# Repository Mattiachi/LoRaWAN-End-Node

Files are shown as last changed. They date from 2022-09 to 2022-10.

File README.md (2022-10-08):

# LoRaWAN-End-Node
Project HW and FW of a LoRaWAN end-node with a low power consumption &lt; 1uW

This project is based on a PIC18LF46K22 and the LoRaWAN transceiver SX1276.
The board is powered up by two AAA batteries in series and stays in sleep with a current of around 50 nA. 
After an amount of time set by the resistance Rext, the timer TPL5010 wakes up the PIC18, wich is responsible of measuring the temperature and sending it to a nearby LoRaWAN gateway via ABP (Activation by Personalization).

With this arrangement, transmitting every 15-30 minutes at the lowest SF possible, the estimated life battery can range between 2 to 8 years.

There is a wake button, wich can instantly wake up the board, a ICSP programming port for PICKIT3 or 4 and two rows of 8 pins (distanced 2.54mm) that allow to solder on top of the PCB the [LoRa Olimex module](https://www.olimex.com/Products/IoT/LoRa/LoRa868/open-source-hardware). 

For further information refer to my [thesis document](https://amslaurea.unibo.it/26629)
where the project is explained in more detail.

MicrosoftTeams-image (10) 3d_view_bakc
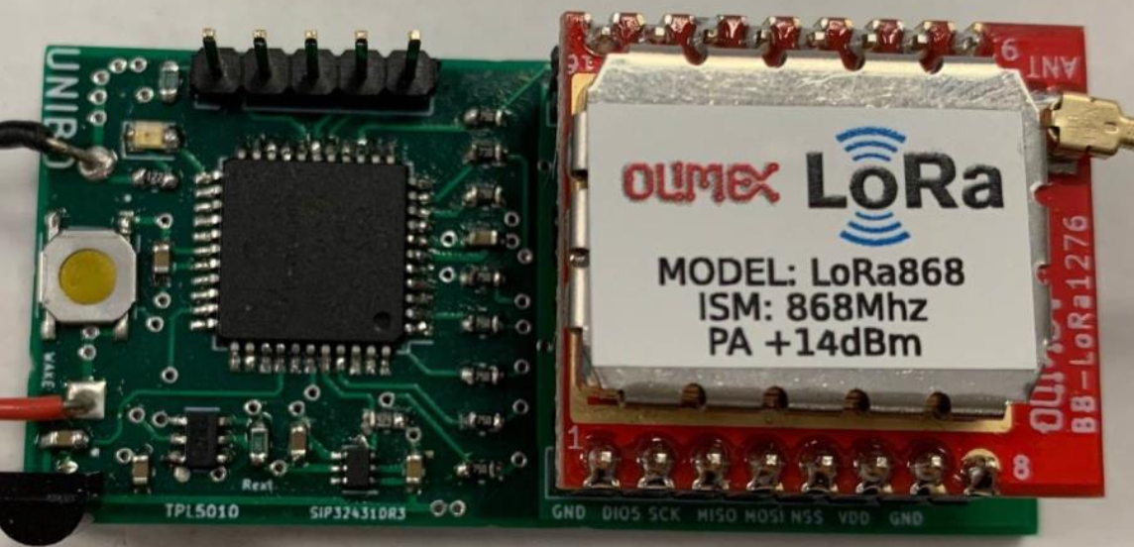
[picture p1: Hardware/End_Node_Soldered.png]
End_Node_Soldered


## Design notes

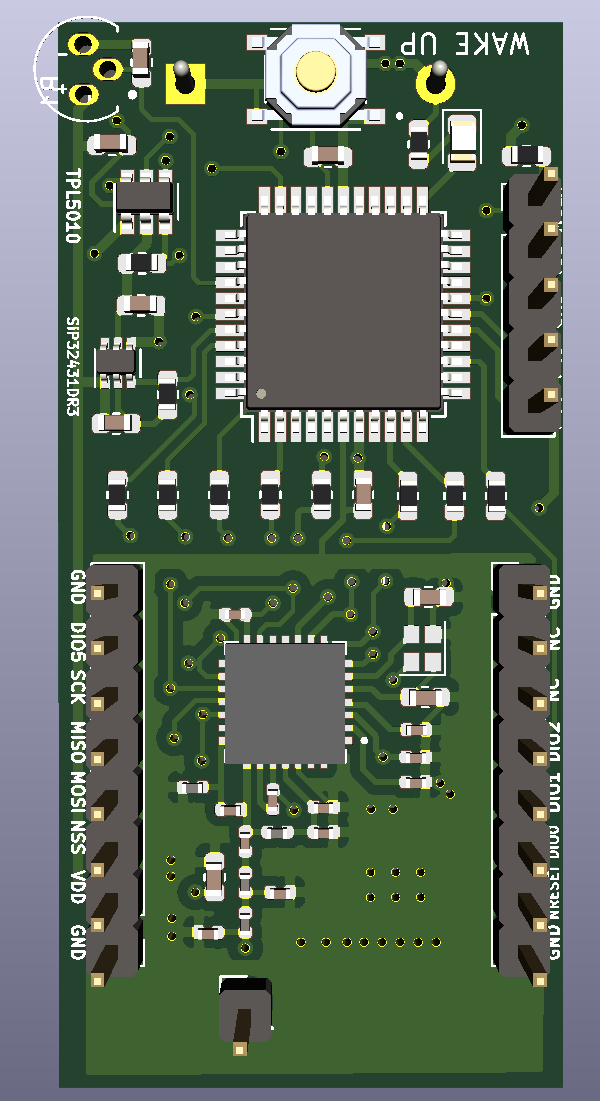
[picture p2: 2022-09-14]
Hardware/3d_view.PNG

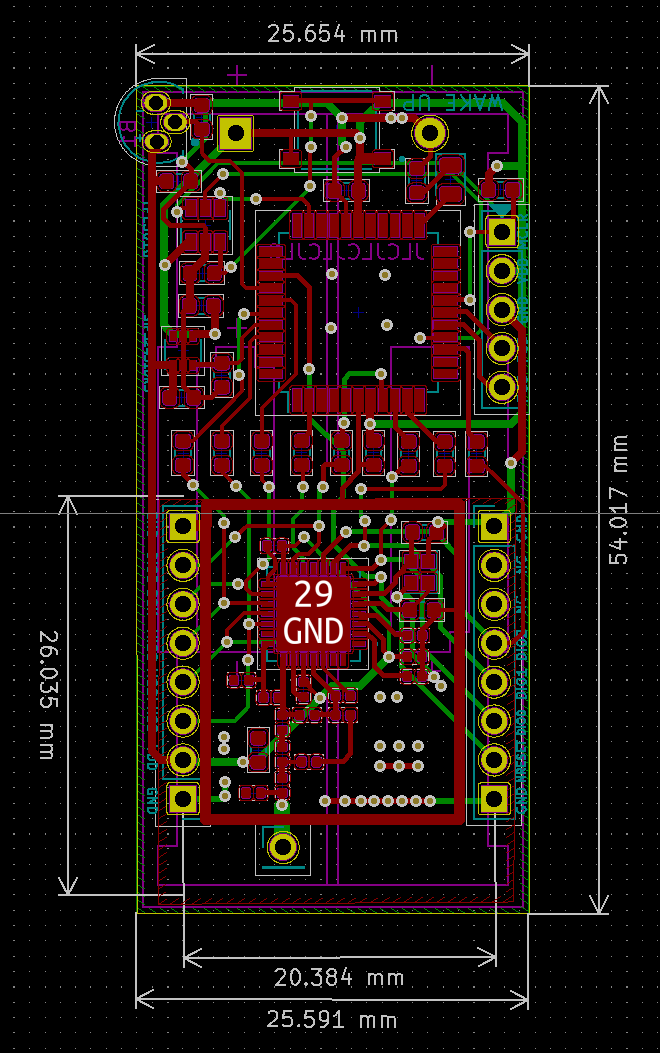
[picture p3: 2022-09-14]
Hardware/layout.PNG

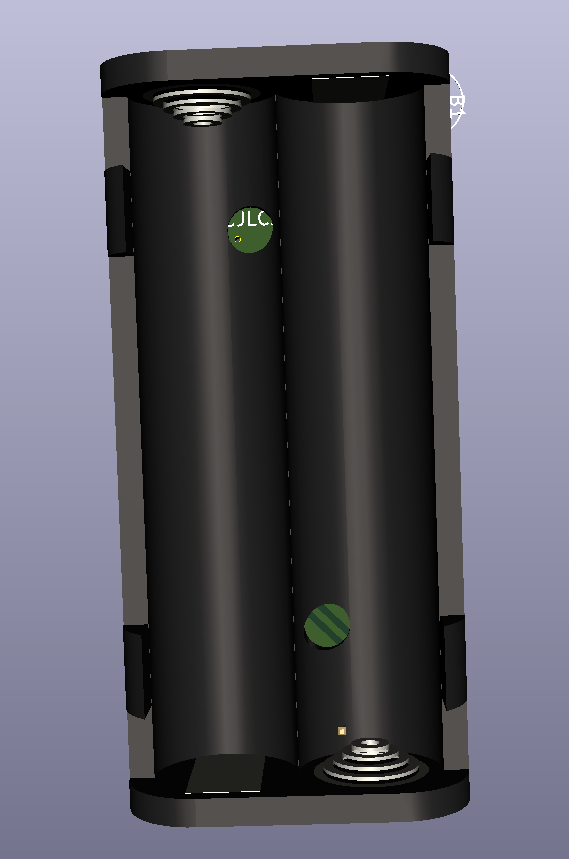
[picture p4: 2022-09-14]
Hardware/3d_view_bakc.PNG

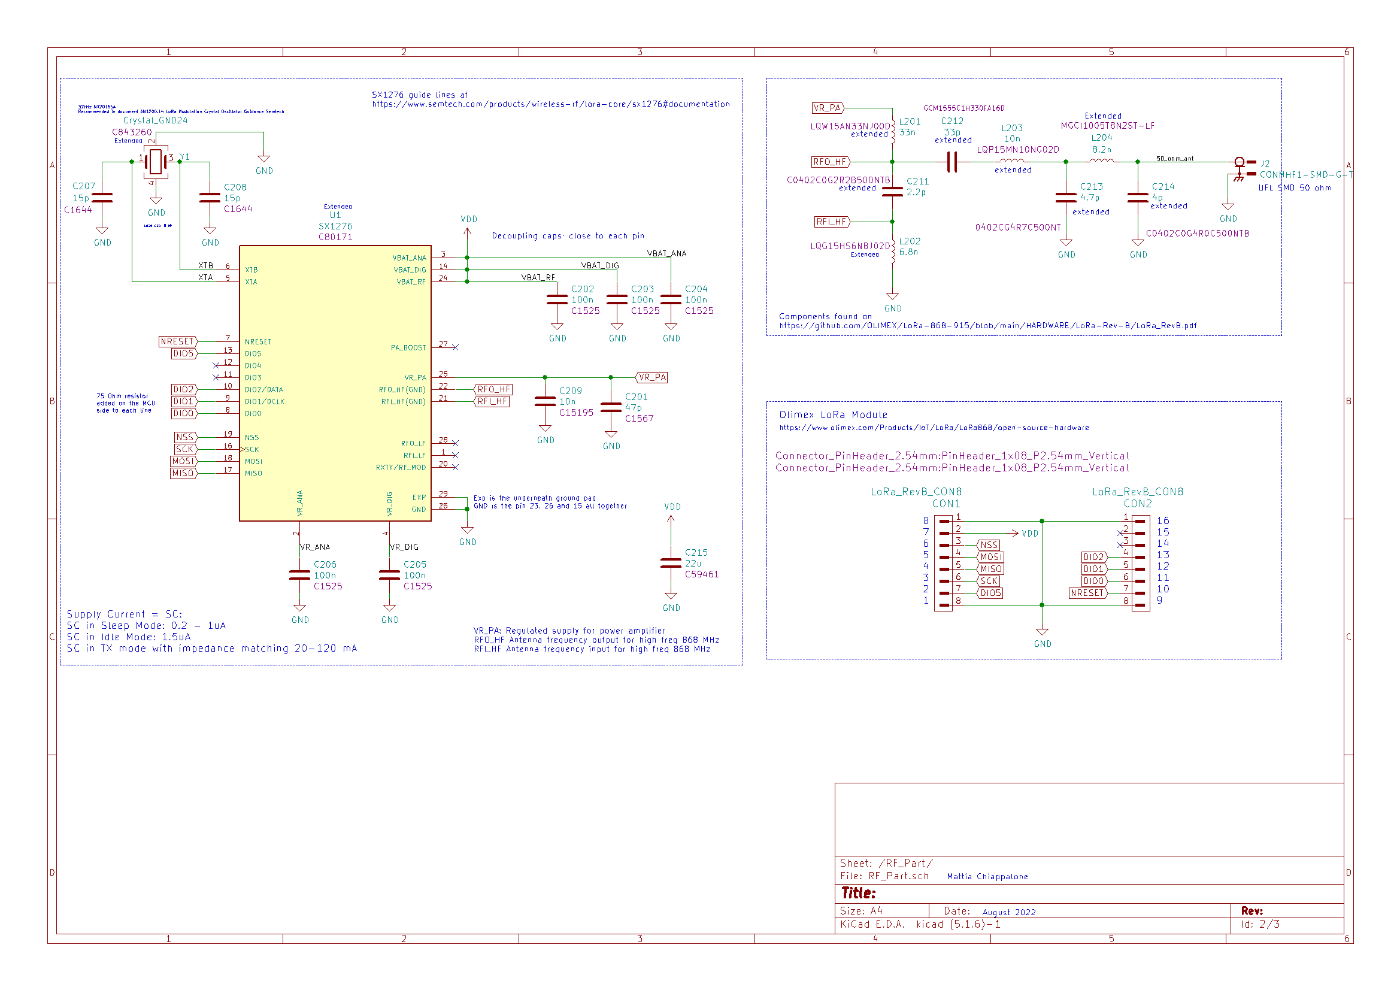
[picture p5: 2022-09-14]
Schematic/RF_part.png

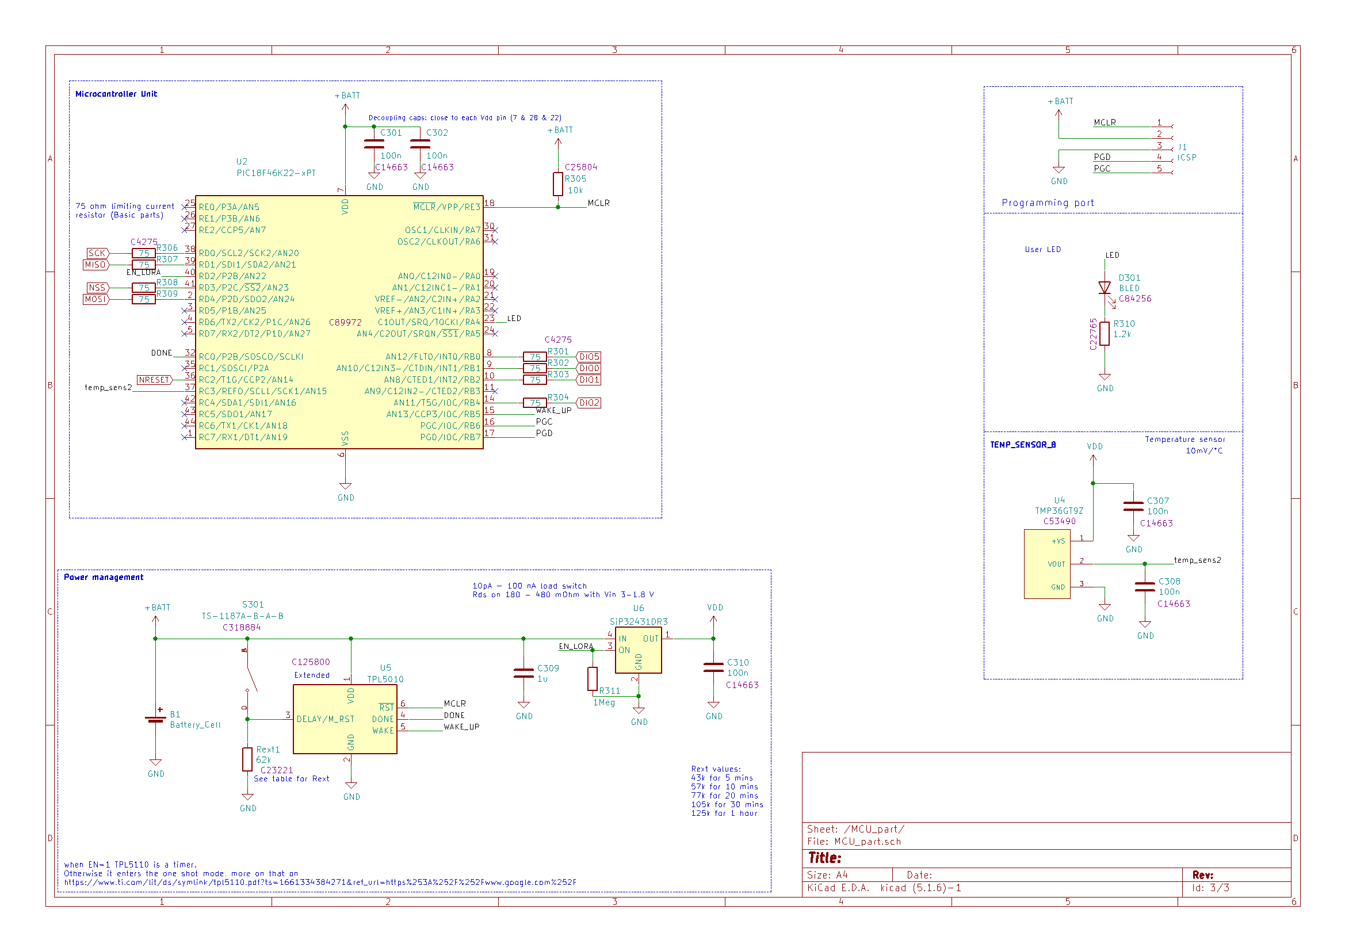
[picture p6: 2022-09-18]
Schematic/mcu.png

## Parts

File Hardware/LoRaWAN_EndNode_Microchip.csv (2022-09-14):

Comment | Designator | Footprint | LCSC | Extended | MPN
Battery_Cell | B1 | Battery_Holders:Keystone_2468_2xAAA |  |  | keystone 2468
47p | C201 | Capacitor_SMD:C_0402_1005Metric | C1567 | No | 0402CG470J500NT
100n | C202,C203,C204,C205,C206 | Capacitor_SMD:C_0402_1005Metric | C1525 | No | CL05B104KO5NNNC
15p | C207,C208 | Capacitor_SMD:C_0603_1608Metric | C1644 | No | CL10C150JB8NNNC
10n | C209 | Capacitor_SMD:C_0402_1005Metric | C15195 | No | CL05B103KB5NNNC
47n | C210 | Capacitor_SMD:C_0603_1608Metric | C1622 | No | CL10B473KB8NNNC
2.2p | C211 | Capacitor_SMD:C_0402_1005Metric | C140673 | Yes | C0402C0G2R2B500NTB
33p | C212 | Capacitor_SMD:C_0402_1005Metric | C437439 | Yes | GCM1555C1H330FA16D
4.7p | C213 | Capacitor_SMD:C_0402_1005Metric | C1569 | No | 0402CG4R7C500NT
4p | C214 | Capacitor_SMD:C_0402_1005Metric | C140662 | Yes | C0402C0G4R0C500NTB
10u | C303 | Capacitor_SMD:C_0603_1608Metric | C96446 | No | CL10A106MA8NRNC
1u | C304,C309 | Capacitor_SMD:C_0603_1608Metric | C15849 | No | CL10A105KB8NNNC
100n | C301,C302,C305,C306,C307,C308,C310 | Capacitor_SMD:C_0603_1608Metric | C14663 | No | CC0603KRX7R9BB104
LoRa_RevB_CON8 | CON1,CON2 | Connector_PinHeader_2.54mm:PinHeader_1x08_P2.54mm_Vertical |  | No
BLED | D301 | LED_SMD:LED_0805_2012Metric | C84256 | No | NCD0805R1
ICSP | J1 | Connector_PinHeader_2.54mm:PinHeader_1x05_P2.54mm_Vertical
Antenna connector | J2 | Connector_PinHeader_2.54mm:PinHeader_1x01_P2.54mm_Vertical
33n | L201 | Inductor_SMD:L_0402_1005Metric | C335624 | Yes | LQW15AN33NJ00D
6.8n | L202 | Inductor_SMD:L_0402_1005Metric | C77110 | Yes | LQG15HS6N8J02D
10n | L203 | Inductor_SMD:L_0402_1005Metric | C162639 | Yes | LQP15MN10NG02D
8.2n | L204 | Inductor_SMD:L_0402_1005Metric | C281010 | Yes | MGCI1005T8N2ST-LF
10k | R305,R311 | Resistor_SMD:R_0603_1608Metric | C25804 | No | 0603WAF1002T5E
75 | R301,R302,R303,R304,R306,R307,R308,R309 | Resistor_SMD:R_0603_1608Metric | C4275 | No | 0603WAF750JT5E
1.2k | R310 | Resistor_SMD:R_0603_1608Metric | C22765 | No | 0603WAF1201T5E
62k | Rext1 | Resistor_SMD:R_0603_1608Metric | C23221 | No | 0603WAF6202T5E
TS-1187A-B-A-B | S301 | SW_TS-1187A-B-A-B | C318884 | No | TS-1187A-B-A-B
SX1276 | U1 | QFN65P600X600X100-29N | C80171 | Yes | SX1276IMLTRT
PIC18F46K22-xPT | U2 | Package_QFP:TQFP-44_10x10mm_P0.8mm | C89972 | Yes | PIC18F46K22-I/PT
MCP9700AT-ETT | U3 | Package_TO_SOT_SMD:SOT-23 | C127949 | Yes | MCP9700AT-E/TT
TMP36GT9Z | U4 | TO92127P521H733-3 | C53490 | Yes | TMP36GT9Z
TPL5010 | U5 | Package_TO_SOT_SMD:SOT-23-6 | C125800 | Yes | TPL5010DDCT
SiP32431DR3 | U6 | Package_TO_SOT_SMD:SOT-363_SC-70-6 | C141606 | Yes | SIP32431DR3-T1GE3
Crystal_GND24 | Y1 | Crystal:Crystal_SMD_2016-4Pin_2.0x1.6mm | C843260 | Yes | NX2016SA-32MHZ-STD-CZS-5

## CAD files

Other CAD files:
FW/dist/default/production/ZZZZZZ.production.obj

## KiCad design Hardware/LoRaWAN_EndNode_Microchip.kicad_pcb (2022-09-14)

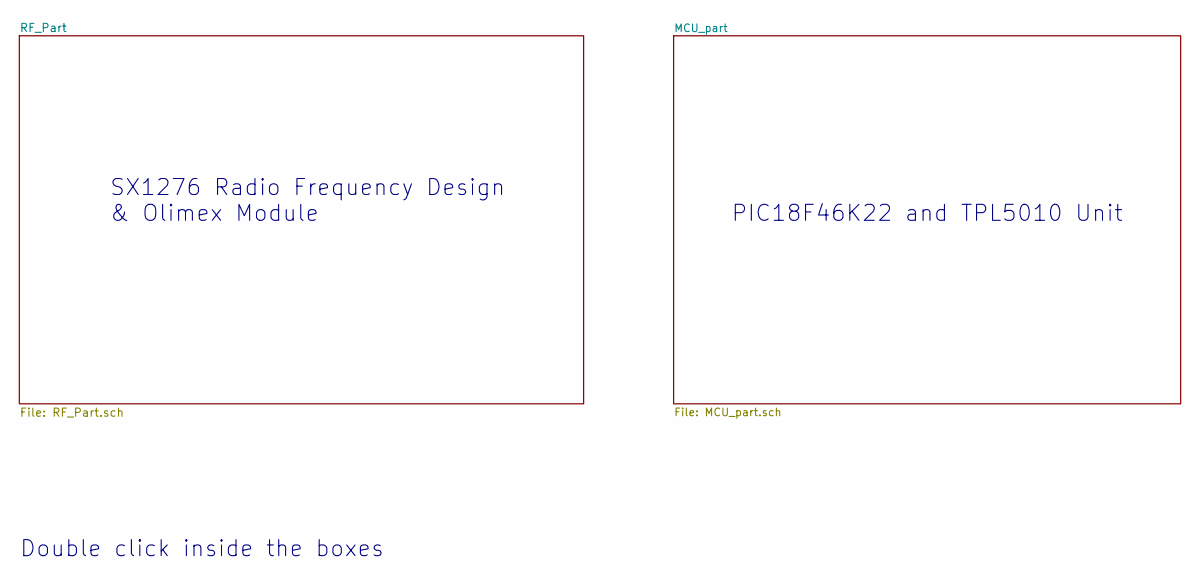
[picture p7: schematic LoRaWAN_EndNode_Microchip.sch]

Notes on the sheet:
SX1276 Radio Frequency Design & Olimex Module
PIC18F46K22 and TPL5010 Unit
Double click inside the boxes

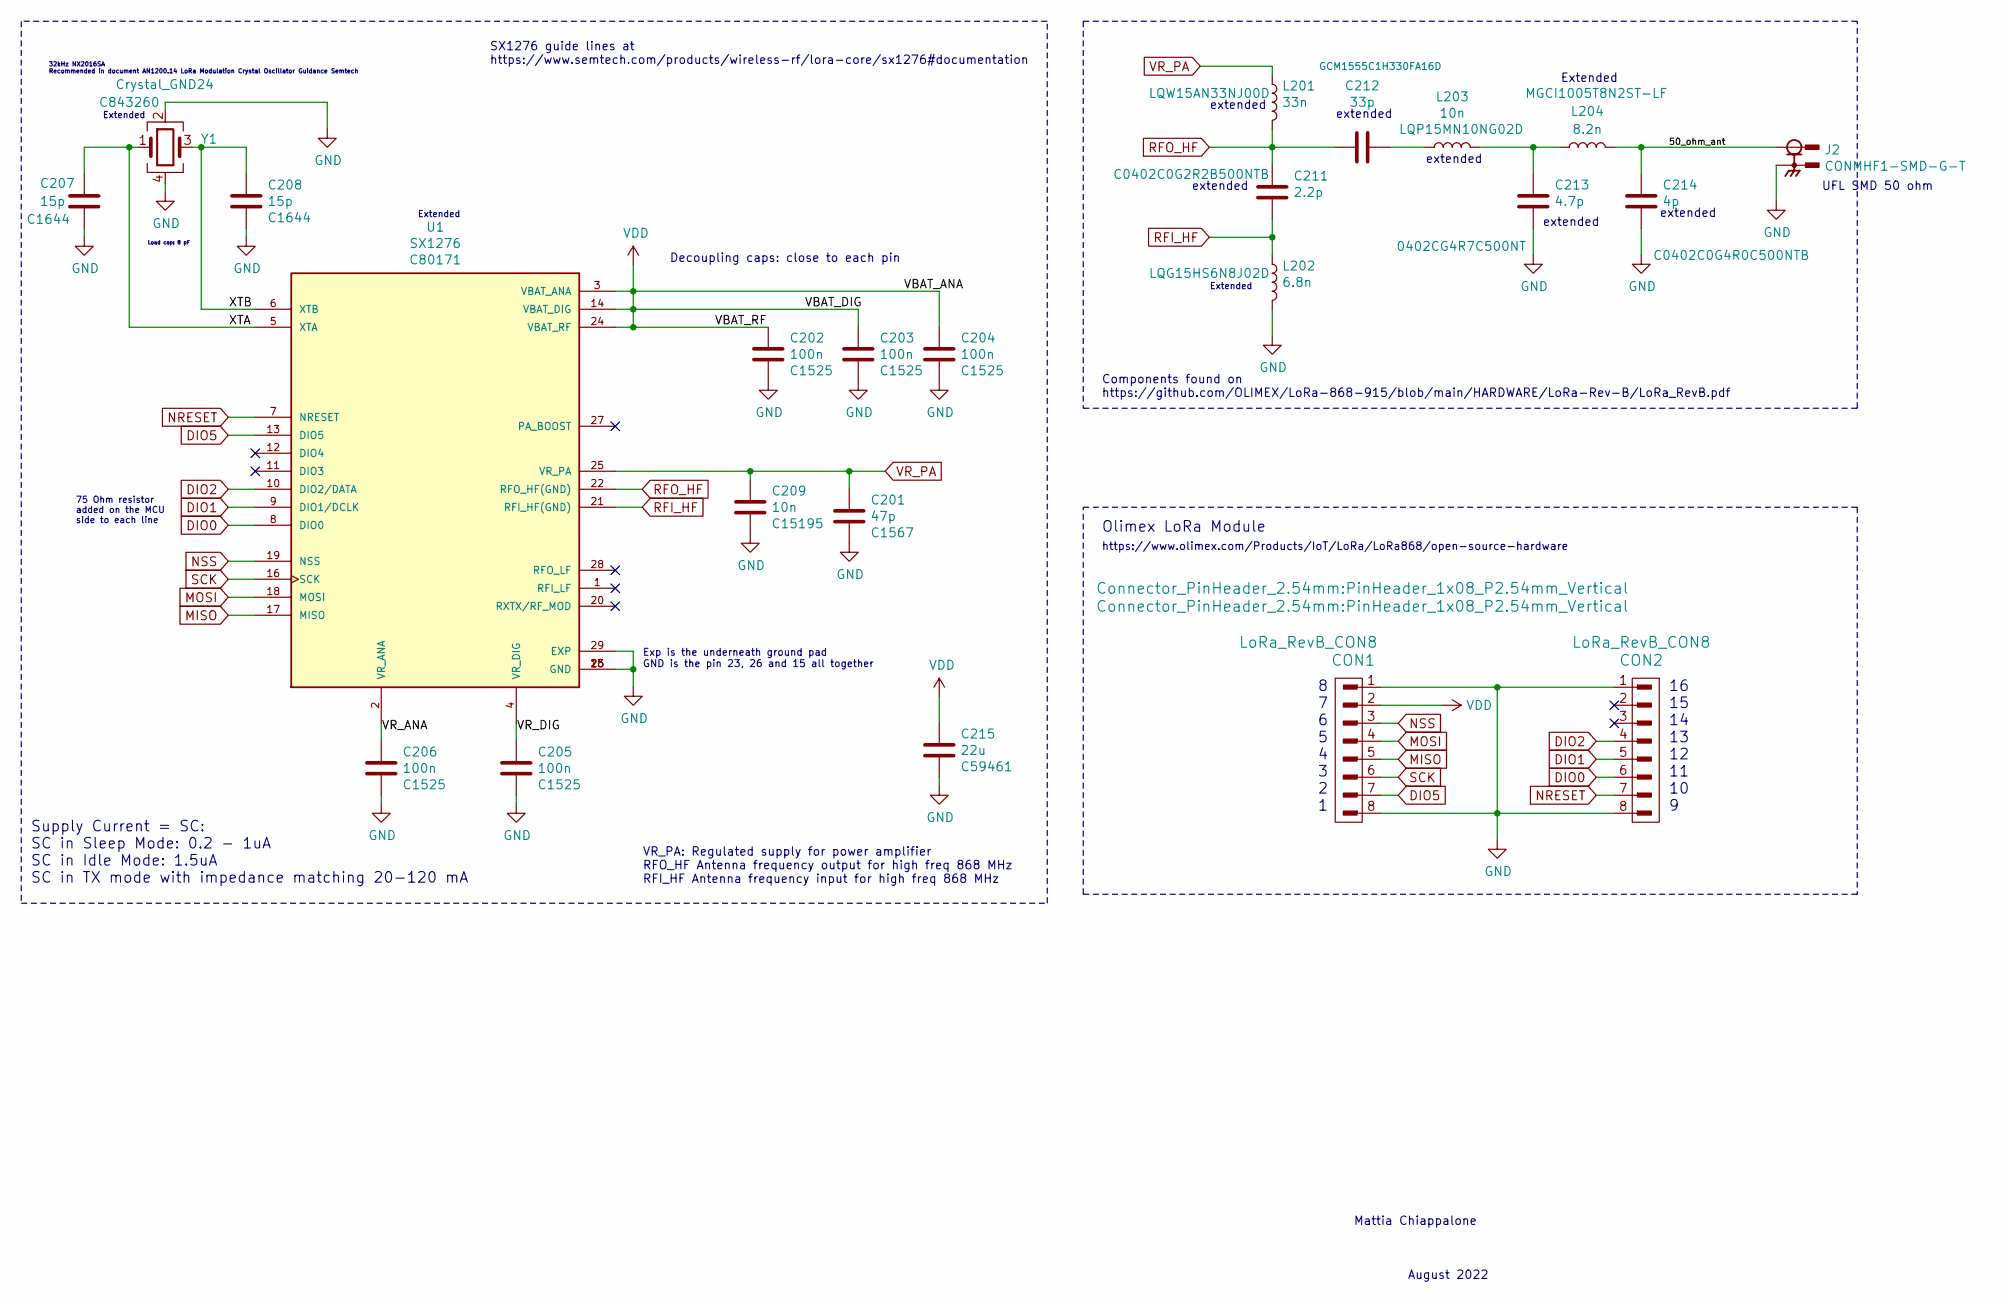
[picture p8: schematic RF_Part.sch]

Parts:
C201: 47p; C_0402_1005Metric; MPN 0402CG470J500NT; LCSC C1567
C202, C203, C204, C205, C206: 100n; C_0402_1005Metric; MPN CL05B104KO5NNNC; LCSC C1525
C207, C208: 15p; C_0603_1608Metric; MPN CL10C150JB8NNNC; LCSC C1644
C209: 10n; C_0402_1005Metric; MPN CL05B103KB5NNNC; LCSC C15195
C211: 2.2p; C_0402_1005Metric; MPN C0402C0G2R2B500NTB; LCSC C140673
C212: 33p; C_0402_1005Metric; MPN GCM1555C1H330FA16D; LCSC C437439
C213: 4.7p; C_0402_1005Metric; MPN 0402CG4R7C500NT; LCSC C1569
C214: 4p; C_0402_1005Metric; MPN C0402C0G4R0C500NTB; LCSC C140662
C215: 22u; C_0603_1608Metric; MPN CL10A226MQ8NRNC; LCSC C59461
CON1, CON2: LoRa_RevB_CON8; PinHeader_1x08_P2.54mm_Vertical
J2: CONMHF1-SMD-G-T; LINX_CONMHF1-SMD-G-T; PARTREV A
L201: 33n; L_0402_1005Metric; MPN LQW15AN33NJ00D; LCSC C335624
L202: 6.8n; L_0402_1005Metric; MPN LQG15HS6N8J02D; LCSC C77110
L203: 10n; L_0402_1005Metric; MPN LQP15MN10NG02D; LCSC C162639
L204: 8.2n; L_0402_1005Metric; MPN MGCI1005T8N2ST-LF; LCSC C281010
U1: SX1276; QFN65P600X600X100-29N; PARTREV 6; LCSC C80171
Y1: Crystal_GND24; Crystal_SMD_2016-4Pin_2.0x1.6mm; MPN NX2016SA-32MHZ-STD-CZS-5; LCSC C843260

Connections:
/RF_Part/50_ohm_ant: C214.2, J2.1, L204.2
/RF_Part/VR_ANA: C206.1, U1.2 (VR_ANA)
/RF_Part/VR_DIG: C205.1, U1.4 (VR_DIG)
/RF_Part/XTA: C207.1, U1.5 (XTA), Y1.1
/RF_Part/XTB: C208.1, U1.6 (XTB), Y1.3
DIO0: CON2.6, U1.8 (DIO0); also elsewhere on the board
DIO1: CON2.5, U1.9 (DIO1/DCLK); also elsewhere on the board
DIO2: CON2.4, U1.10 (DIO2/DATA); also elsewhere on the board
DIO5: CON1.7, U1.13 (DIO5); also elsewhere on the board
GND: C201.2, C202.2, C203.2, C204.2, C205.2, C206.2, C207.2, C208.2, C209.2, C213.1, C214.1, C215.2, CON1.1, CON1.8, CON2.1, CON2.8, J2.S1, J2.S2, J2.S3, L202.2, U1.15 (GND), U1.23 (GND), U1.26 (GND), U1.29 (EXP), Y1.2, Y1.4; also elsewhere on the board
MISO: CON1.5, U1.17 (MISO); also elsewhere on the board
MOSI: CON1.4, U1.18 (MOSI); also elsewhere on the board
NRESET: CON2.7, U1.7 (NRESET); also elsewhere on the board
NSS: CON1.3, U1.19 (NSS); also elsewhere on the board
unnamed: C212.1, L203.1
unnamed: C213.2, L203.2, L204.1
RFI_HF: C211.2, L202.1, U1.21 (RFI_HF(GND))
RFO_HF: C211.1, C212.2, L201.2, U1.22 (RFO_HF(GND))
SCK: CON1.6, U1.16 (SCK); also elsewhere on the board
VDD: C202.1, C203.1, C204.1, C215.1, CON1.2, U1.3 (VBAT_ANA), U1.14 (VBAT_DIG), U1.24 (VBAT_RF); also elsewhere on the board
VR_PA: C201.1, C209.1, L201.1, U1.25 (VR_PA)

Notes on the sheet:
Exp is the underneath ground pad GND is the pin 23, 26 and 15 all together
32kHz NX2016SA Recommended in document AN1200.14 LoRa Modulation Crystal Oscillator Guidance Semtech
Load cap: 8 pF
SX1276 guide lines at https://www.semtech.com/products/wireless-rf/lora-core/sx1276#documentation
Supply Current = SC: SC in Sleep Mode: 0.2 - 1uA SC in Idle Mode: 1.5uA SC in TX mode with impedance matching 20-120 mA
Decoupling caps: close to each pin
VR_PA: Regulated supply for power amplifier RFO_HF Antenna frequency output for high freq 868 MHz RFI_HF Antenna frequency input for high freq 868 MHz
August 2022
Mattia Chiappalone
Extended
Extended
75 Ohm resistor added on the MCU side to each line
extended
extended
Components found on https://github.com/OLIMEX/LoRa-868-915/blob/main/HARDWARE/LoRa-Rev-B/LoRa_RevB.pdf
8 7 6 5 4 3 2 1
16 15 14 13 12 11 10 9
Olimex LoRa Module
https://www.olimex.com/Products/IoT/LoRa/LoRa868/open-source-hardware
UFL SMD 50 ohm

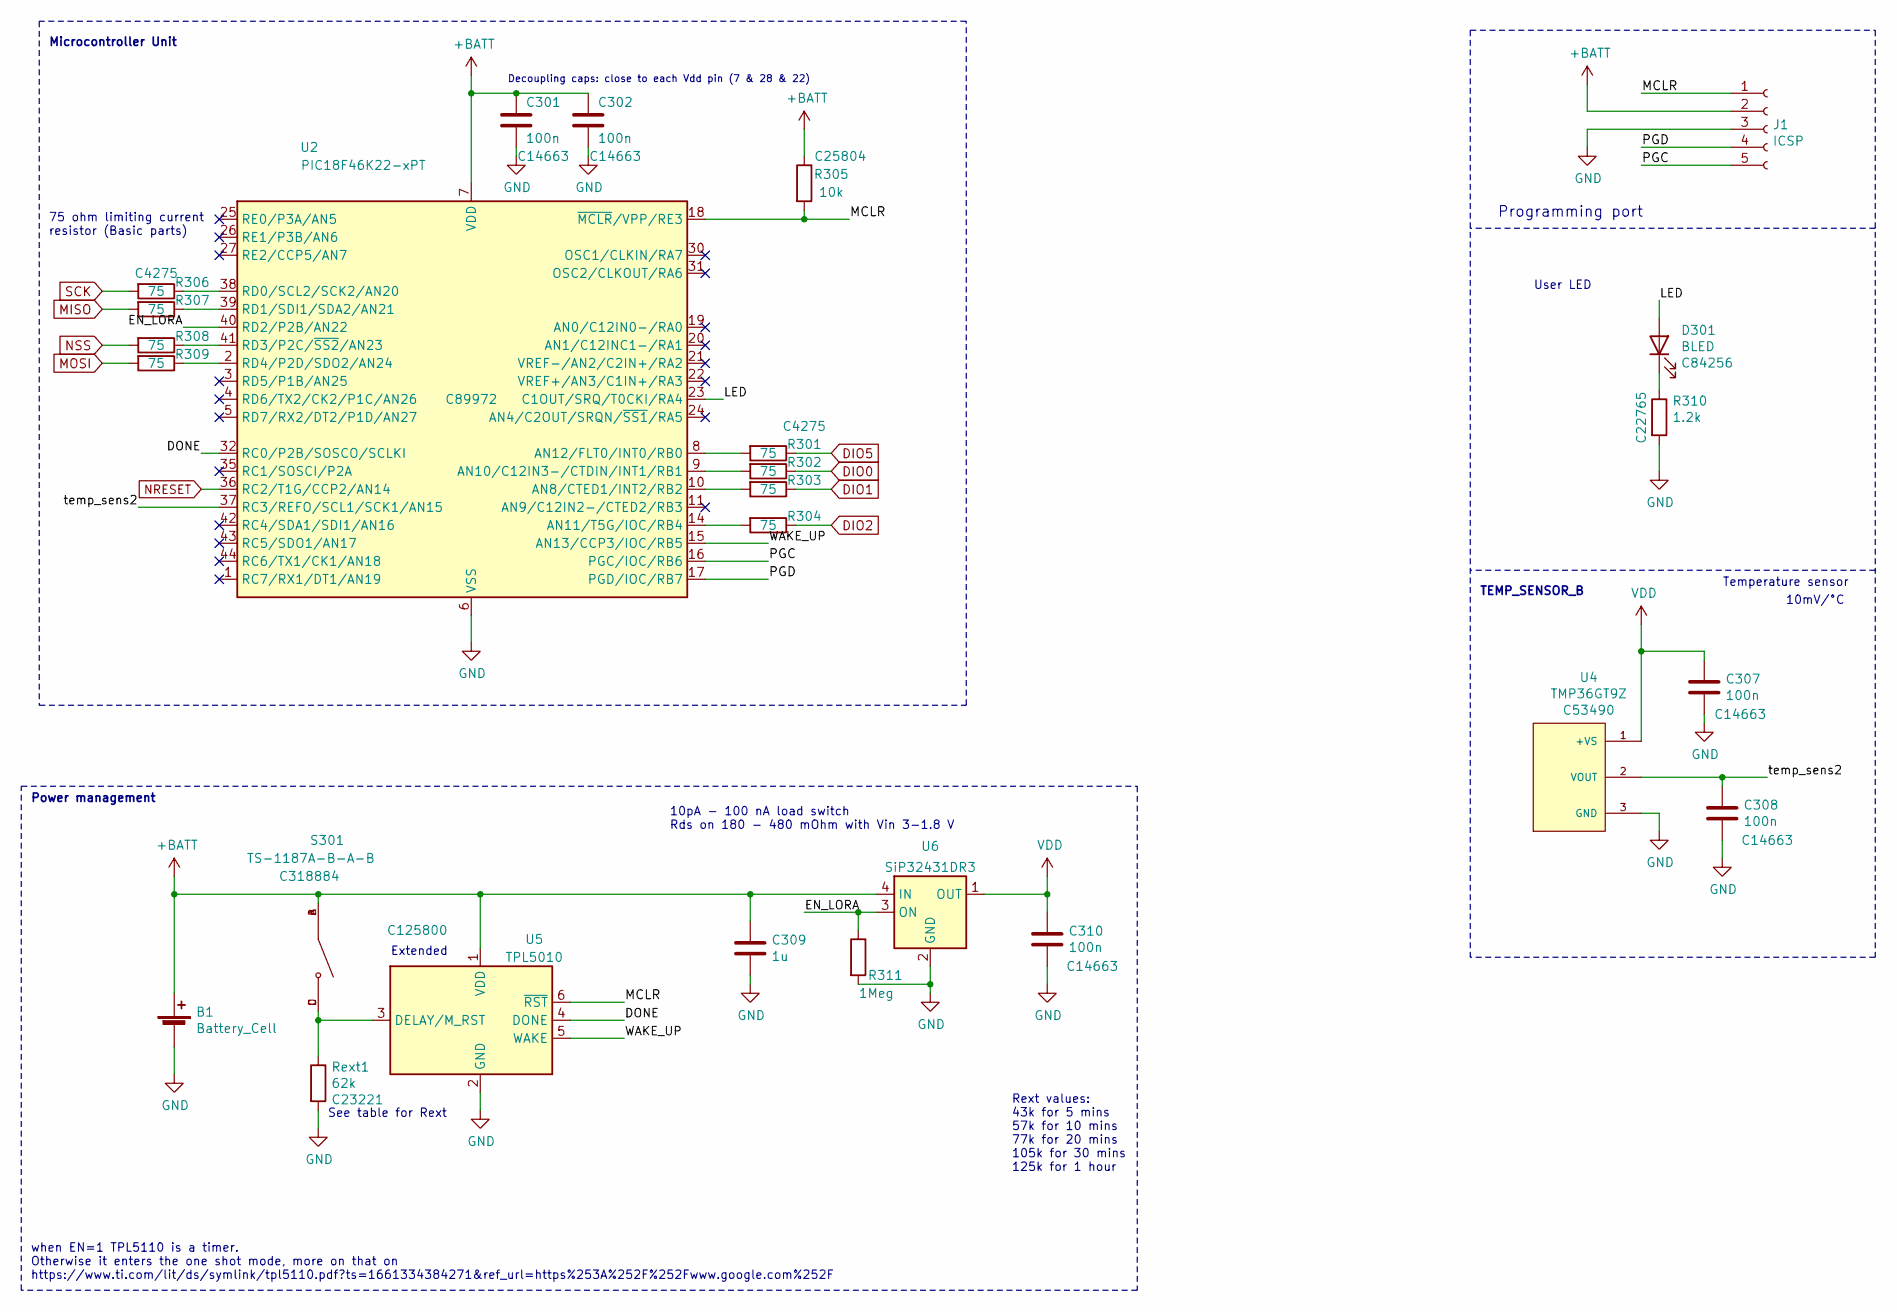
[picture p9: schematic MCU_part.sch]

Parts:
B1: Battery_Cell; BatteryHolder_Keystone_2468_2xAAA; MPN 2468
C301, C302, C307, C308, C310: 100n; C_0603_1608Metric; MPN CC0603KRX7R9BB104; LCSC C14663
C309: 1u; C_0603_1608Metric; MPN CC0603KRX7R7BB105
D301: BLED; LED_0805_2012Metric; MPN NCD0805R1; LCSC C84256
J1: ICSP; PinHeader_1x05_P2.54mm_Vertical
R301, R302, R303, R304, R306, R307, R308, R309: 75; R_0603_1608Metric; MPN 0603WAF750JT5E; LCSC C4275
R305: 10k; R_0603_1608Metric; MPN 0603WAF1002T5E; LCSC C25804
R310: 1.2k; R_0603_1608Metric; MPN 0603WAF1201T5E; LCSC C22765
R311: 1Meg; R_0603_1608Metric; MPN 0603WAF1002T5E; LCSC C25804
Rext1: 62k; R_0603_1608Metric; MPN 0603WAF6202T5E; LCSC C23221
S301: TS-1187A-B-A-B; SW_TS-1187A-B-A-B; PARTREV A0; LCSC C318884
U2: PIC18F46K22-xPT; TQFP-44_10x10mm_P0.8mm; MPN PIC18F46K22-I/PT; LCSC C89972
U4: TMP36GT9Z; TO92127P521H733-3; PARTREV H; LCSC C53490
U5: TPL5010; SOT-23-6; MPN TPL5010DDCT; LCSC C125800
U6: SiP32431DR3; SOT-363_SC-70-6; MPN SIP32431DR3-T1GE3; LCSC C141606

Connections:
+BATT: B1.1 (+), C301.1, C302.1, C309.1, J1.2, R305.1, S301.A, S301.B, U2.7 (VDD), U2.28 (VDD), U5.1 (VDD), U6.4 (IN)
/MCU_part/DONE: U2.32 (RC0/P2B/SOSCO/SCLKI), U5.4 (DONE)
/MCU_part/EN_LORA: R311.1, U2.40 (RD2/P2B/AN22), U6.3 (ON)
/MCU_part/LED: D301.2 (A), U2.23 (C1OUT/SRQ/T0CKI/RA4)
/MCU_part/MCLR: J1.1, R305.2, U2.18 (~MCLR~/VPP/RE3), U5.6 (~RST)
/MCU_part/PGC: J1.5, U2.16 (PGC/IOC/RB6)
/MCU_part/PGD: J1.4, U2.17 (PGD/IOC/RB7)
/MCU_part/WAKE_UP: U2.15 (AN13/CCP3/IOC/RB5), U5.5 (WAKE)
/MCU_part/temp_sens2: C308.2, U2.37 (RC3/REFO/SCL1/SCK1/AN15), U4.2 (VOUT)
DIO0: R302.1; also elsewhere on the board
DIO1: R303.1; also elsewhere on the board
DIO2: R304.1; also elsewhere on the board
DIO5: R301.1; also elsewhere on the board
GND: B1.2 (-), C301.2, C302.2, C307.1, C308.1, C309.2, C310.2, J1.3, R310.2, R311.2, Rext1.2, U2.6 (VSS), U2.29 (VSS), U4.3 (GND), U5.2 (GND), U6.2 (GND), U6.5 (GND); also elsewhere on the board
MISO: R307.2; also elsewhere on the board
MOSI: R309.2; also elsewhere on the board
NRESET: U2.36 (RC2/T1G/CCP2/AN14); also elsewhere on the board
NSS: R308.2; also elsewhere on the board
unnamed: D301.1 (K), R310.1
unnamed: R301.2, U2.8 (AN12/FLT0/INT0/RB0)
unnamed: R302.2, U2.9 (AN10/C12IN3-/CTDIN/INT1/RB1)
unnamed: R303.2, U2.10 (AN8/CTED1/INT2/RB2)
unnamed: R304.2, U2.14 (AN11/T5G/IOC/RB4)
unnamed: R306.1, U2.38 (RD0/SCL2/SCK2/AN20)
unnamed: R307.1, U2.39 (RD1/SDI1/SDA2/AN21)
unnamed: R308.1, U2.41 (RD3/P2C/~SS2~/AN23)
unnamed: R309.1, U2.2 (RD4/P2D/SDO2/AN24)
unnamed: Rext1.1, S301.C, S301.D, U5.3 (DELAY/M_RST)
SCK: R306.2; also elsewhere on the board
VDD: C307.2, C310.1, U4.1 (+VS), U6.1 (OUT); also elsewhere on the board

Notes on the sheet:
Decoupling caps: close to each Vdd pin (7 & 28 & 22)
Programming port
75 ohm limiting current resistor (Basic parts)
Temperature sensor
10mV/°C
TEMP_SENSOR_B
when EN=1 TPL5110 is a timer. Otherwise it enters the one shot mode, more on that on https://www.ti.com/lit/ds/symlink/tpl5110.pdf?ts=1661334384271&ref_url=https%253A%252F%252Fwww.google.com%252F
Power management
Microcontroller Unit
Extended
10pA - 100 nA load switch Rds on 180 - 480 mOhm with Vin 3-1.8 V
Rext values: 43k for 5 mins 57k for 10 mins 77k for 20 mins 105k for 30 mins 125k for 1 hour
See table for Rext
User LED

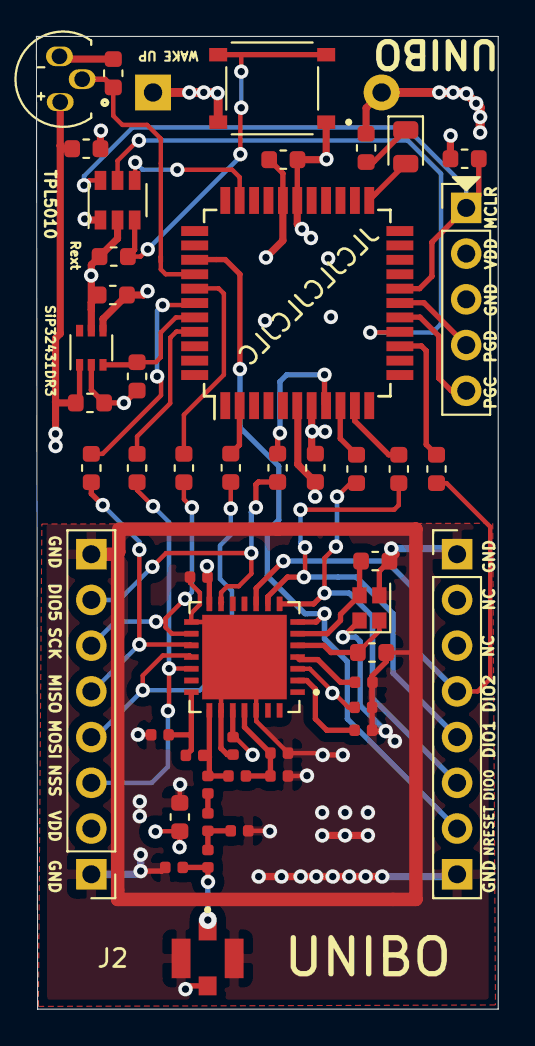
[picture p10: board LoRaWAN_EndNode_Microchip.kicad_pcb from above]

Board: 4 copper layers, 25.7 x 54.0 mm, 49 parts (1 on the bottom side), 40 nets.

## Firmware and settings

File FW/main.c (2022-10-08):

/* Author:  Chiappalone Mattia
 * Date:    September 2022
 * Main:    Il PIC inizializza allo start up lo stack LoRaWAN, poi entra
 *          in un ciclo infinito dove legge il sensore di temperatura,
 *          invia il pacchetto al server LoRaWAN e poi va in sleep fino a
 *          che non verrà svegliato dal timer TPL5010 tramite pin IOC. 
 * 
 * Tested:          Wake up funzionante, Invio e ricezione dati dal server
 *
 * Not Tested:      Comunicazione bidirezionale, deep sleep @20nA con tutte
 *                  le periferiche disabilitate
 *
*/

#include "mcc_generated_files/mcc.h"

// Functions i wrote
void readAndSend(void);
void SysConfigSleep(void);
void SysRestoreFromSleep(void);
void LoRaSleep (void); 
void LoRaWakeUp(void); 

// Variables
int portNumber = 2;
uint16_t payload[1];
uint8_t TimeToSend;
uint8_t JoinedServer = 0;
int count = 1;          // Number of packets sent

// Premade functions for LoRaWAN & variables
uint8_t nwkSKey[16] = {0x75, 0xE0, 0x66, 0x1A, 0xA0, 0xBC, 0x21, 0xE4, 0x4B, 0x57, 0x21, 0xB0, 0xD6, 0x30, 0xF7, 0xB2};
uint8_t appSKey[16] = {0xDD, 0x32, 0x54, 0xF0, 0x8D, 0x55, 0xD6, 0x52, 0xE7, 0x73, 0x0B, 0xBC, 0x26, 0x3E, 0x0A, 0xDA};
uint32_t devAddr = 0x12345678;
void RxDataDone(uint8_t* pData, uint8_t dataLength, OpStatus_t status);
void RxJoinResponse(bool status);

void main(void)
{
    // Initialize the device
    SYSTEM_Initialize();
    SysConfigSleep();
    printf("\n\rSystem Initialized\n\r");
    EN_LORA_SetHigh();
    printf("\n\rPowering up SX1276 module\n\r");
    
    INTERRUPT_GlobalInterruptEnable();
    INTERRUPT_PeripheralInterruptEnable();

    printf("Initializing LoRaWAN Stack\n\r");
    LORAWAN_Init(RxDataDone, RxJoinResponse);
    LORAWAN_SetNetworkSessionKey(nwkSKey);
    LORAWAN_SetApplicationSessionKey(appSKey);
    LORAWAN_SetDeviceAddress(devAddr);
    LORAWAN_Join(ABP);
    printf("LoRaWAN Stack Initialized\n\r");
    
    //PORTAbits.RA4 = 1;  //Led turned on
    LED_SetHigh();
    TimeToSend = 1;
    
    while(JoinedServer == 0){   // While the network isnt join do nothing...
        LORAWAN_Mainloop();
    }
    
    while (1)
    {   
        PORTAbits.RA4 = 1;
        LORAWAN_Mainloop();
        
        if(TimeToSend == 1){
            printf("It's time to send a packet...\n\r");
            readAndSend();
            TimeToSend = 0;
        }
        
        if(LORAWAN_GetState() == IDLE){   // it's not transmitting nor receiving
            DONE_SetHigh();                    // Warns the timer TPL5010 that we are done (otherwise a reset could be applied to the MCU)
            printf("Done pulled high..\n\r");
            EN_LORA_SetLow(); 
            printf("Powering off SX1276 module\n\r");
            __delay_ms(1);
            printf("Going to sleep!\n\r");
            DONE_SetLow();               // The Done signal must be held high for at least 100 nS
            //SysConfigSleep();
            LoRaSleep(); 
            PORTAbits.RA4 = 0;
            SLEEP();   
            
            //SysRestoreFromSleep();
            EN_LORA_SetHigh();
            printf("\n\r");
            printf("I'm awake!\n\r");
            LoRaWakeUp(); 
            printf("Powering up SX1276 module\n\r");
            TimeToSend = 1;
        }
        
        
    } // End of while
} // End of main



void RxDataDone(uint8_t* pData, uint8_t dataLength, OpStatus_t status)
{
}

void RxJoinResponse(bool status)
{   
    printf("Callback function! LoRaWAN Initialized successfully\n\r");
    JoinedServer = 1;
    //PORTAbits.RA4 = 0; //LEd turned off
    LED_SetLow();
}

void readAndSend(void){
    ADCON0bits.ADON = 1;
    //while(ADC_GetConversion(TEMP) < 300);
    payload[0] = ADC_GetConversion(TEMP);
    //payload[0] = 0xFF00;
    LORAWAN_Send(UNCNF, portNumber, &payload, sizeof(payload)); 
    printf("Packet #%d sent: temperature value: %d\n\r", count, payload[0]);
    count++;
    
}

void SysConfigSleep(void)
{
    // Turn off everything the project won't ever use
    ADCON0bits.ADON = 0;
    UART2MD = 1;
    //UART1MD = 1;
    TMR6MD = 1;
    TMR5MD = 1;    
    TMR4MD = 1;
    TMR2MD = 1;
    //TMR1MD = 1;
    //MSSP2MD = 1;
    MSSP1MD = 1;

    CCP5MD = 1;
    CCP4MD = 1;
    CCP3MD = 1;
    CCP2MD = 1;
    CCP1MD = 1;
    CTMUMD = 1;
    CMP2MD = 1;
    CMP1MD = 1;
    
    //Device enters Sleep mode on SLEEP instruction
    IDLEN = 0;
    
    // Configure as output all unused port pins and set them to low
    //PORT A
    
    /*TRISA = 0x00;
    LATA = 0x00;
    
    //PORT B
    TRISBbits.RB4 = OUTPUT;
    TRISBbits.RB5 = OUTPUT;
    TRISBbits.RB6 = OUTPUT;
    TRISBbits.RB7 = OUTPUT;
    LATBbits.LATB4 = LOW;
    LATBbits.LATB5 = LOW;
    LATBbits.LATB6 = LOW;
    LATBbits.LATB7 = LOW;
    
    //PORT C
    TRISCbits.RC0 = OUTPUT;
    TRISCbits.RC1 = OUTPUT;
    TRISCbits.RC3 = OUTPUT;
    TRISCbits.RC4 = OUTPUT;
    TRISCbits.RC5 = OUTPUT;
    TRISCbits.RC6 = OUTPUT;
    TRISCbits.RC7 = OUTPUT;
    LATCbits.LATC0 = LOW;
    LATCbits.LATC1 = LOW;
    LATCbits.LATC3 = LOW;
    LATCbits.LATC4 = LOW;
    LATCbits.LATC5 = LOW;
    LATCbits.LATC6 = LOW;
    LATCbits.LATC7 = LOW;
    
    //PORT D
    TRISDbits.RD0 = OUTPUT;
    TRISDbits.RD1 = OUTPUT;
    TRISDbits.RD2 = OUTPUT;
    TRISDbits.RD4 = OUTPUT;
    TRISDbits.RD5 = OUTPUT;
    TRISDbits.RD7 = OUTPUT;
    LATDbits.LATD0 = LOW;
    LATDbits.LATD1 = LOW;
    LATDbits.LATD2 = LOW;
    LATDbits.LATD4 = LOW;
    LATDbits.LATD5 = LOW;
    LATDbits.LATD7 = LOW;
    
    //PORT E
    TRISEbits.RE0 = OUTPUT;
    TRISEbits.RE1 = OUTPUT;
    TRISEbits.RE2 = OUTPUT;
    LATEbits.LATE0 = LOW;
    LATEbits.LATE1 = LOW;
    LATEbits.LATE2 = LOW;
}

void SysRestoreFromSleep(){
    LATE = 0x00;    
    LATD = 0x00;    
    LATA = 0x00;    
    LATB = 0x00;    
    LATC = 0x00;    

    
    TRISx registers
     
    TRISE = 0x07;
    TRISA = 0xEF;
    TRISB = 0xFF;
    TRISC = 0xBE;
    TRISD = 0xE2;

    /**
    ANSELx registers
      
    ANSELC = 0xB8;
    ANSELB = 0x08;
    ANSELD = 0xE0;
    ANSELE = 0x07;
    ANSELA = 0x2F;
    
    */
    //EUSART1_Initialize();
}

void LoRaSleep (void) 
{
    // SSPEN disabled; WCOL no_collision; SSPOV no_overflow; CKP Idle:Low, Active:High; SSPM FOSC/4;
    SSP2CON1 = 0x00;
    
    //Disable MSSP2 module
    MSSP2MD = 1;
    
    //Make sure SPI2 pins are not left in floating state during sleep
    //NCS
    RADIO_nCS_ANS = 0;
    RADIO_nCS_TRIS = 0;
    RADIO_nCS_LAT = 1;
    
    //MISO
    ANSD1 = 0;
    TRISD1 = 0;
    LATD1 = 0;
    
    //MOSI
    ANSD4 = 0;
    TRISD4 = 0;
    LATD4 = 0;
    
    //CLK
    ANSD0 = 0;
    TRISD0 = 0;
    LATD0 = 0;
}

void LoRaWakeUp(void) 
{   
    MSSP2MD = 0;    
    SPI2_Initialize();
}
/**
End of File
*/

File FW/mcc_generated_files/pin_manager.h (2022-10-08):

/**
  @Generated Pin Manager Header File

  @Company:
    Microchip Technology Inc.

  @File Name:
    pin_manager.h

  @Summary:
    This is the Pin Manager file generated using MPLAB(c) Code Configurator

  @Description:
    This header file provides implementations for pin APIs for all pins selected in the GUI.
    Generation Information :
        Product Revision  :  MPLAB(c) Code Configurator - 4.0
        Device            :  PIC18LF46K22
        Version           :  1.01
    The generated drivers are tested against the following:
        Compiler          :  XC8 1.35
        MPLAB             :  MPLAB X 3.40

    Copyright (c) 2013 - 2015 released Microchip Technology Inc.  All rights reserved.

    Microchip licenses to you the right to use, modify, copy and distribute
    Software only when embedded on a Microchip microcontroller or digital signal
    controller that is integrated into your product or third party product
    (pursuant to the sublicense terms in the accompanying license agreement).

    You should refer to the license agreement accompanying this Software for
    additional information regarding your rights and obligations.

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
*/


#ifndef PIN_MANAGER_H
#define PIN_MANAGER_H

#define INPUT   1
#define OUTPUT  0

#define HIGH    1
#define LOW     0

#define ANALOG      1
#define DIGITAL     0

#define PULL_UP_ENABLED      1
#define PULL_UP_DISABLED     0

// get/set LED aliases
#define LED_TRIS               TRISAbits.TRISA4
#define LED_LAT                LATAbits.LATA4
#define LED_PORT               PORTAbits.RA4
#define LED_SetHigh()            do { LATAbits.LATA4 = 1; } while(0)
#define LED_SetLow()             do { LATAbits.LATA4 = 0; } while(0)
#define LED_Toggle()             do { LATAbits.LATA4 = ~LATAbits.LATA4; } while(0)
#define LED_GetValue()           PORTAbits.RA4
#define LED_SetDigitalInput()    do { TRISAbits.TRISA4 = 1; } while(0)
#define LED_SetDigitalOutput()   do { TRISAbits.TRISA4 = 0; } while(0)

// get/set RB0 procedures
#define RB0_SetHigh()    do { LATBbits.LATB0 = 1; } while(0)
#define RB0_SetLow()   do { LATBbits.LATB0 = 0; } while(0)
#define RB0_Toggle()   do { LATBbits.LATB0 = ~LATBbits.LATB0; } while(0)
#define RB0_GetValue()         PORTBbits.RB0
#define RB0_SetDigitalInput()   do { TRISBbits.TRISB0 = 1; } while(0)
#define RB0_SetDigitalOutput()  do { TRISBbits.TRISB0 = 0; } while(0)
#define RB0_SetPullup()     do { WPUBbits.WPUB0 = 1; } while(0)
#define RB0_ResetPullup()   do { WPUBbits.WPUB0 = 0; } while(0)
#define RB0_SetAnalogMode() do { ANSELBbits.ANSB0 = 1; } while(0)
#define RB0_SetDigitalMode()do { ANSELBbits.ANSB0 = 0; } while(0)

// get/set RB1 procedures
#define RB1_SetHigh()    do { LATBbits.LATB1 = 1; } while(0)
#define RB1_SetLow()   do { LATBbits.LATB1 = 0; } while(0)
#define RB1_Toggle()   do { LATBbits.LATB1 = ~LATBbits.LATB1; } while(0)
#define RB1_GetValue()         PORTBbits.RB1
#define RB1_SetDigitalInput()   do { TRISBbits.TRISB1 = 1; } while(0)
#define RB1_SetDigitalOutput()  do { TRISBbits.TRISB1 = 0; } while(0)
#define RB1_SetPullup()     do { WPUBbits.WPUB1 = 1; } while(0)
#define RB1_ResetPullup()   do { WPUBbits.WPUB1 = 0; } while(0)
#define RB1_SetAnalogMode() do { ANSELBbits.ANSB1 = 1; } while(0)
#define RB1_SetDigitalMode()do { ANSELBbits.ANSB1 = 0; } while(0)

// get/set RB2 procedures
#define RB2_SetHigh()    do { LATBbits.LATB2 = 1; } while(0)
#define RB2_SetLow()   do { LATBbits.LATB2 = 0; } while(0)
#define RB2_Toggle()   do { LATBbits.LATB2 = ~LATBbits.LATB2; } while(0)
#define RB2_GetValue()         PORTBbits.RB2
#define RB2_SetDigitalInput()   do { TRISBbits.TRISB2 = 1; } while(0)
#define RB2_SetDigitalOutput()  do { TRISBbits.TRISB2 = 0; } while(0)
#define RB2_SetPullup()     do { WPUBbits.WPUB2 = 1; } while(0)
#define RB2_ResetPullup()   do { WPUBbits.WPUB2 = 0; } while(0)
#define RB2_SetAnalogMode() do { ANSELBbits.ANSB2 = 1; } while(0)
#define RB2_SetDigitalMode()do { ANSELBbits.ANSB2 = 0; } while(0)

// get/set RB4 procedures
#define RB4_SetHigh()    do { LATBbits.LATB4 = 1; } while(0)
#define RB4_SetLow()   do { LATBbits.LATB4 = 0; } while(0)
#define RB4_Toggle()   do { LATBbits.LATB4 = ~LATBbits.LATB4; } while(0)
#define RB4_GetValue()         PORTBbits.RB4
#define RB4_SetDigitalInput()   do { TRISBbits.TRISB4 = 1; } while(0)
#define RB4_SetDigitalOutput()  do { TRISBbits.TRISB4 = 0; } while(0)
#define RB4_SetPullup()     do { WPUBbits.WPUB4 = 1; } while(0)
#define RB4_ResetPullup()   do { WPUBbits.WPUB4 = 0; } while(0)
#define RB4_SetAnalogMode() do { ANSELBbits.ANSB4 = 1; } while(0)
#define RB4_SetDigitalMode()do { ANSELBbits.ANSB4 = 0; } while(0)

// get/set WAKE_UP aliases
#define WAKE_UP_TRIS               TRISBbits.TRISB5
#define WAKE_UP_LAT                LATBbits.LATB5
#define WAKE_UP_PORT               PORTBbits.RB5
#define WAKE_UP_WPU                WPUBbits.WPUB5
#define WAKE_UP_ANS                ANSELBbits.ANSB5
#define WAKE_UP_SetHigh()            do { LATBbits.LATB5 = 1; } while(0)
#define WAKE_UP_SetLow()             do { LATBbits.LATB5 = 0; } while(0)
#define WAKE_UP_Toggle()             do { LATBbits.LATB5 = ~LATBbits.LATB5; } while(0)
#define WAKE_UP_GetValue()           PORTBbits.RB5
#define WAKE_UP_SetDigitalInput()    do { TRISBbits.TRISB5 = 1; } while(0)
#define WAKE_UP_SetDigitalOutput()   do { TRISBbits.TRISB5 = 0; } while(0)
#define WAKE_UP_SetPullup()      do { WPUBbits.WPUB5 = 1; } while(0)
#define WAKE_UP_ResetPullup()    do { WPUBbits.WPUB5 = 0; } while(0)
#define WAKE_UP_SetAnalogMode()  do { ANSELBbits.ANSB5 = 1; } while(0)
#define WAKE_UP_SetDigitalMode() do { ANSELBbits.ANSB5 = 0; } while(0)

// get/set DONE aliases
#define DONE_TRIS               TRISCbits.TRISC0
#define DONE_LAT                LATCbits.LATC0
#define DONE_PORT               PORTCbits.RC0
#define DONE_SetHigh()            do { LATCbits.LATC0 = 1; } while(0)
#define DONE_SetLow()             do { LATCbits.LATC0 = 0; } while(0)
#define DONE_Toggle()             do { LATCbits.LATC0 = ~LATCbits.LATC0; } while(0)
#define DONE_GetValue()           PORTCbits.RC0
#define DONE_SetDigitalInput()    do { TRISCbits.TRISC0 = 1; } while(0)
#define DONE_SetDigitalOutput()   do { TRISCbits.TRISC0 = 0; } while(0)

// get/set RC2 procedures
#define RC2_SetHigh()    do { LATCbits.LATC2 = 1; } while(0)
#define RC2_SetLow()   do { LATCbits.LATC2 = 0; } while(0)
#define RC2_Toggle()   do { LATCbits.LATC2 = ~LATCbits.LATC2; } while(0)
#define RC2_GetValue()         PORTCbits.RC2
#define RC2_SetDigitalInput()   do { TRISCbits.TRISC2 = 1; } while(0)
#define RC2_SetDigitalOutput()  do { TRISCbits.TRISC2 = 0; } while(0)
#define RC2_SetAnalogMode() do { ANSELCbits.ANSC2 = 1; } while(0)
#define RC2_SetDigitalMode()do { ANSELCbits.ANSC2 = 0; } while(0)
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
